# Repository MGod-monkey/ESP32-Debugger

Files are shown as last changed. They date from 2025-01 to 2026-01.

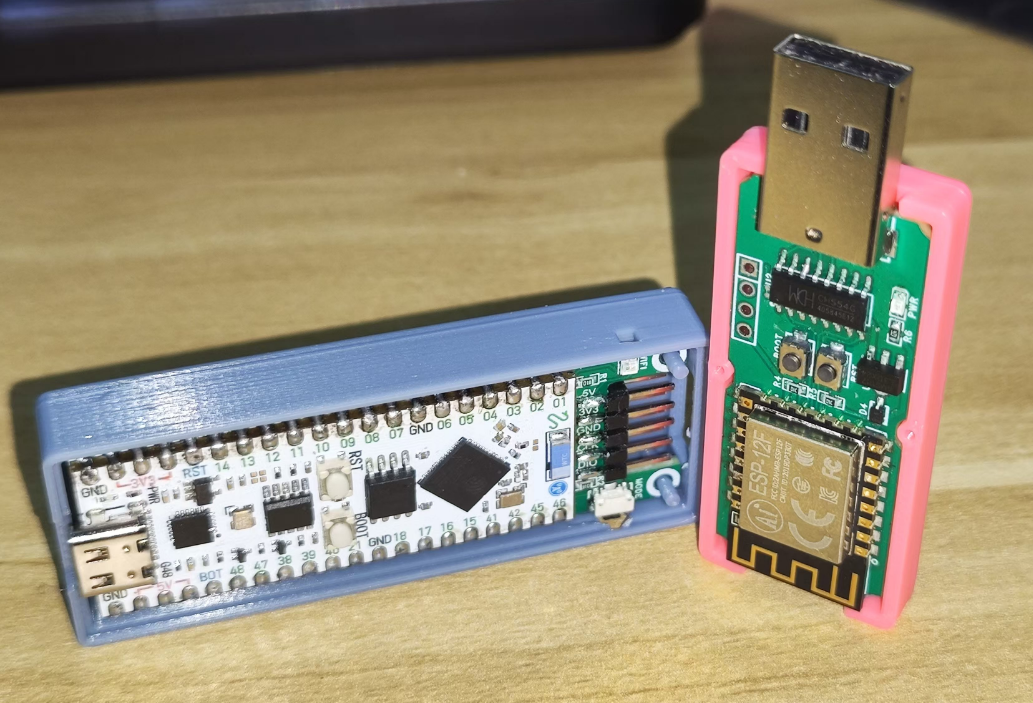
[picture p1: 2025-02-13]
assets/Snipaste_2024-12-25_23-06-20.png

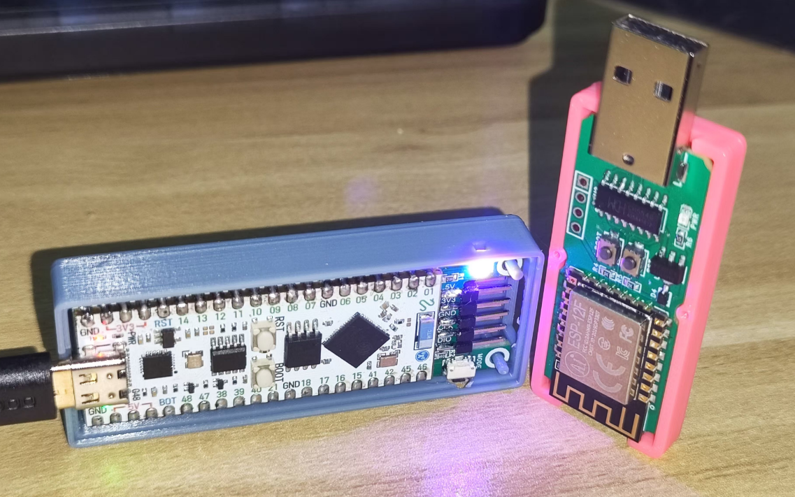
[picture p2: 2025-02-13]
assets/Snipaste_2024-12-25_23-15-52.png

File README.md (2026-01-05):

> 代码基于ESP-IDF v5.x开发，Keil工程基于MDK-ARM v5.29开发，其他版本未测试
> 本项目基于MIT协议开源，欢迎大家使用和转载，转载请注明出处
>

[toc]

## B站演示视频：[【（开源）基于ESP32S3立创开发板的多功能调试器（STM32 / ESP32 / Arduino调试和烧录）】 ](https://www.bilibili.com/video/BV1NECJYyEaa/?share_source=copy_web&vd_source=be68408916a9ed6715c50a7c23ca43b6)

## 项目简介

1. 接收机基于立创ESP32S3R8N8开发板制作，可独立运行，也可搭配发送机运行，接收机可以搭配发送机实现即插即用，无需上位机和WIFI，即可远程调试和开发
2. 接收机支持支持SWD和JTAG协议，支持 OpenOCD/pyOCD，支持虚拟串口，可同时进行仿真调试和串口收发
3. 接收机支持有线调试和无线调试的切换，通过MODE按钮长按进行模式切换
4. 接收机内置Web服务，可通过访问接收机IP来实现简单的WebSerial调试
5. 接收机支持向目标板供电（5V、3.3V），以及从目标板取电（5V、3.3V）两种方式进行工作
6. 接收机带状态指示灯，可提示当前调试模式，WIFI信号强度等
7. 烧录速度大于10KB/s，串口通信波特率可设置1M及以上
8. 接收机支持使用串口给Arduino等设备烧录固件，支持Arduino的串口烧录协议

## 实物展示
| 实物正面图 | 实物背面图 |
| --- | --- |
|  |  |





## 原理解析（硬件说明）


	本项目的发送端硬件由**CH554G单片机**和**ESP12F无线模块**组成。CH554G 是一款兼容 MCS51 指令集并支持 USB 2.0 的高性能单片机，主要负责与PC端进行USB 通信。通过USB连接PC，生成 **CMSIS DAP调试设备**和**CDC 虚拟串口设备**，提供调试和串口通信功能。同时，CH554G通过UART与ESP12F无线模块连接。ESP12F 负责**创建无线热点（AP）**并**搭建 TCP 服务器**，等待接收端设备连接，从而实现数据的**无线透传**功能，**CHECK信号线**用于判断是否与**接收机建立连接**。**SY6280AAC**用于**防止意外过压**或**过流**导致的电路损坏，保障系统的安全性和稳定性，限流大小为**I(A)=6800/R2=1A**。



	接收端硬件主要由立创**ESP32S3R8N8 开发板**构成，通过移植 **DAPLink** 代码实现 **CMSIS-DAP** 功能，用于支持 **SWD** 和 **JTAG** 协议的调试功能。在有线调试模式下，基于**TinyUSB框架**实现USB通信功能，其中 **CMSIS-DAP** 设备和 **CDC 虚拟串口**设备通过TinyUSB的**HID**和**CDC**模块完成初始化和数据传输，支持在PC端的 Keil 环境中进行调试和串口通信。
	同时，接收机还实现了无线调试功能，利用 ESP32S3内置的**Wi-Fi模块**，连接到发送端创建的AP热点，并与**TCP服务器**建立连接，实现**无线数据传输**，从而支持无线下载调试和串口透传。
	此外，接收端还支持**独立运行**，通过连接到与PC端相同的Wi-Fi网络，在局域网内与PC端建立连接，结合**USBIP技术栈**（通过网络远程共享和访问USB设备的一种技术)，可以实现**远程调试**和**串口透传**功能，也能结合**elaphureLink上位机**实现快速的连接和keil的远程下载调试。

## 软件烧录
### 发送机烧录
	1.发送端需要烧录ESP12F和CH554G的固件，CH554G需要使用`WCHISPTool_Setup`烧录工具进行烧录，如果是全新的CH554G，默认插上电脑的USB，上电就会进入Boot模式，此时可以通过工具进行识别和烧录，如果是已经烧录过的CH554G则需要短接U2旁边的触点，然后插上电脑上电，才能通过工具进行烧录，烧录固件为`firmware/ch554.hex`





	ESP12F烧录通过引出来的串口接口进行烧录，需要用一个USB转TTL下载工具，使用乐鑫官方下载工具flash_download_tool进行烧录，长按BOOT按钮，然后短按RST按钮，松开BOOT按钮即可进入ESP12F的下载模式



	`flash_download_tool`选择ESP8266, 然后选择固件`firmware/ESP12F.ion.bin`进行烧录，如果点击开始后没反应，先判断一下串口是否连接对了，再判断一下ESP12F是否进入的下载模式





	烧录完成后，重新接入电脑，发送机就可以正常使用了，此时ESP12F会生成一个AP热点，热点名称：`MGodmonkey`,密码：`1234567890`（后续会考虑给ESP12F添加OTA更新的功能，让其烧录一次代码就能无限远程更新）

### 接收机烧录
	接收机的固件有两种，一个是搭配USBIP技术栈独立使用的单机模式固件，一个是搭配发送机使用的双机模式固件，两种固件下载方式都是一样的。
`flash_download_tool`选择ESP32S3, LoadMode选择UART,ESP32S3立创开发板连接电脑后会生成两个串口，一个是USB-OTG的USB串行设备，一个是连接CH340K的串口设备，选择第二个串口进行烧录即可





	`flash_download_tool`的分区设置要严格按照图中的进行设置，否则可能会出错，烧录的固件在`firmware/Single_Mode`或`firmware/Double_Mode`中

| 文件 |  索引 |
| :---: | :-----: |
| bootloader.bin | 0x0 |
|  ESP32_DAPLink.bin | 0x20000 |
| partition-table.bin  | 0x8000  |
| ota_data_initial.bin | 0xf000  |



## 外壳说明
发送机的外壳可以在淘宝上买到公版的电流计亚克力外壳来使用：
https://item.taobao.com/item.htm?_u=l2otn78942e7&id=536932505082&spm=a1z09.2.0.0.6b752e8dQAsOIG

## 接线方式
根据接收机上的引脚进行接线

SW协议接线：

| 符号  | 对应引脚 |
| :---: | :---: |
|  3V3  | 3V3 |
|  GND  | GND |
| SWDIO | DIO |
| SWCLK | CLK |

JTAG协议接线：

|  符号  | 对应引脚 |
| :----: | :---: |
|  3V3 | 3V3 |
|  GND | GND |
|  TMS | DIO |
|  TCK | CLK |
|  TDI | TDI |
|  TDO | TDO |
| nRESET | RST（可不接） |

UART接线：

| 符号 | 对应引脚 |
| :--: | :---: |
| TXD  | TXD |
| RXD  | RXD |

## 指示灯说明

| 指示灯 | 状态 |
| :---: | :---: |
|  橙色呼吸 | 启动中 |
| 橙色闪烁2次 | 模式切换中 |
|  紫色常亮 | 有线模式 |
|  红色常亮 | 等待连接WIFI / 启动错误 |
|  绿色常亮 | 连接WIFI成功并信号很好  |
|  绿色呼吸 | 连接WIFI成功并信号一般  |
|  红色闪烁 | 连接WIFI成功并信号较差  |

## 使用步骤

> **Keil MDK-ARM**版本需要**5.29**及以上版本，其他软件暂未测试

### 单接收机使用

1. 有线模式（SWD/JTAG）

   有线模式下直接连接usb到电脑上即可，另一边通过SWD/JATG连接待调试的设备，启动成功后会在电脑上生成一个U盘，这是DAPLink的特性（但离线文件下载功能还没实现，，，所以暂时还不能通过传固件文件到u盘上来实现自动烧录），同时会生成一个虚拟串口
   
   

	此时打开keil工程，点击魔法棒->debug->Use选择CMSIS-DAP Debugger->点击Settings后即可看到设备信息，值得说明的是，JTAG协议下有个小bug，就是有时会显示**SWD/JTAG Communication Failure**，此时**Max Clock**设置为**5MHz或低于10MHz下的任意频率**即可，然后就能正常显示设备了，此时也能正常切换回10MHz下的频率进行使用了（应该是软件代码问题，暂未找到bug原因）





2. 有线模式（UART）

   串口支持接收发，支持在SWD/JTAG调试下一起使用，串口频率可以任意设置，可设置到超过1M波特率

   xx

3.无线模式(SWD/JTAG)

	单机无线模式下keil需要搭配开源上位机`elaphureLink`（`elaphureLink`不支持JTAG协议）或者USBIP（支持SWD/JTAG协议）来使用。双击`elaphureLink.Wpf.exe`打开软件，第一次使用需要安装keil驱动，由于代码已经设置好了mDNS，因此无需知道设备IP也可直接连接



	打开keil工程，点击魔法棒->debug->Use选择CMSIS-DAP Debugger->点击Settings后即可看到设备信息



	USBIP使用需要知道提前ESP32S3的IP地址，并且与ESP32S3同一网络下，有线连接开发板，串口助手连接CH340K开头的设备串口即可看到ESP32S3的串口调试信息，成功连接WIFI后会显示IP地址，一般情况下这个IP不会改变，如果家里设备情况多的话，路由器可能会给其重新分配一个IP，此时就需要重新获取了



	**cmd终端**中输入`.\usbip.exe attach -r 设备IP -b 1-1`即可连接设备并且在设备管理器中即可看到生成的**无线CMSIS-DAP**，打开keil工程，点击魔法棒->debug->Use选择CMSIS-DAP Debugger->点击Settings后即可看到设备信息

xxx



4.无线模式(UART)

无线串口传输跟有线串口传输功能是一样的，不过接收机内置了一个Web服务，可以通过访问ESP32S3的IP地址来使用**WebSerial**功能，在网页上发送数据到接收机的串口中



### 搭配发送机使用

> 发送机能实现单接收机的所有功能，只不过接收机自带WIFI，无需上位机和局域网，通过ESP12F与ESP32S3的WIFI模块进行通信，实现远程下载调试和串口传输
>

## WIFI配置说明

### 默认WIFI配置
接收机的WIFI配置位于 `main/include/wifi_configuration.h` 文件中，默认预置了3个WIFI信息：

1. 发送机AP热点 (默认优先级最高)
   - SSID: `MGodmonkey`
   - 密码: `1234567890`

2. 备用热点
   - SSID: `DAP`
   - 密码: `12345678`

3. 实验室网络
   - SSID: `INSS-Lab_2.4G`
   - 密码: `G-STAR1211`

### 使用说明
- 接收机会按顺序尝试连接配置文件中的WIFI
- 单机模式使用时，需要确保能连接到其中一个WIFI
- 可以通过以下方式添加自己的WIFI

## 注意事项

* 如果仅需要单机使用，直接打样接收机的板子即可
* 单机模式需要搭配`elaphureLink`或`usbip`来使用
* 接收机3D外壳底座的按键部分打印出来需要轻轻的向外掰，注意是轻轻的哦

## 总结

> 该项目是匆匆忙忙赶工期造出来的，因为本人处于研究生开题阶段，也在忙着找创新点，经历过的应该都知道这个阶段的苦哈，项目基本功能已经实现，但还有很多bug和不足，后续会慢慢补充和完善
> 本项目借鉴了以下优秀的开源项目：
>
> - [https://github.com/windowsair/wireless-esp8266-dap](https://github.com/windowsair/wireless-esp8266-dap)
> - [ttps://oshwhub.com/q837877663/duo-gong-neng-wu-xian-xia-zai-qi](https://oshwhub.com/q837877663/duo-gong-neng-wu-xian-xia-zai-qi)
> - []()

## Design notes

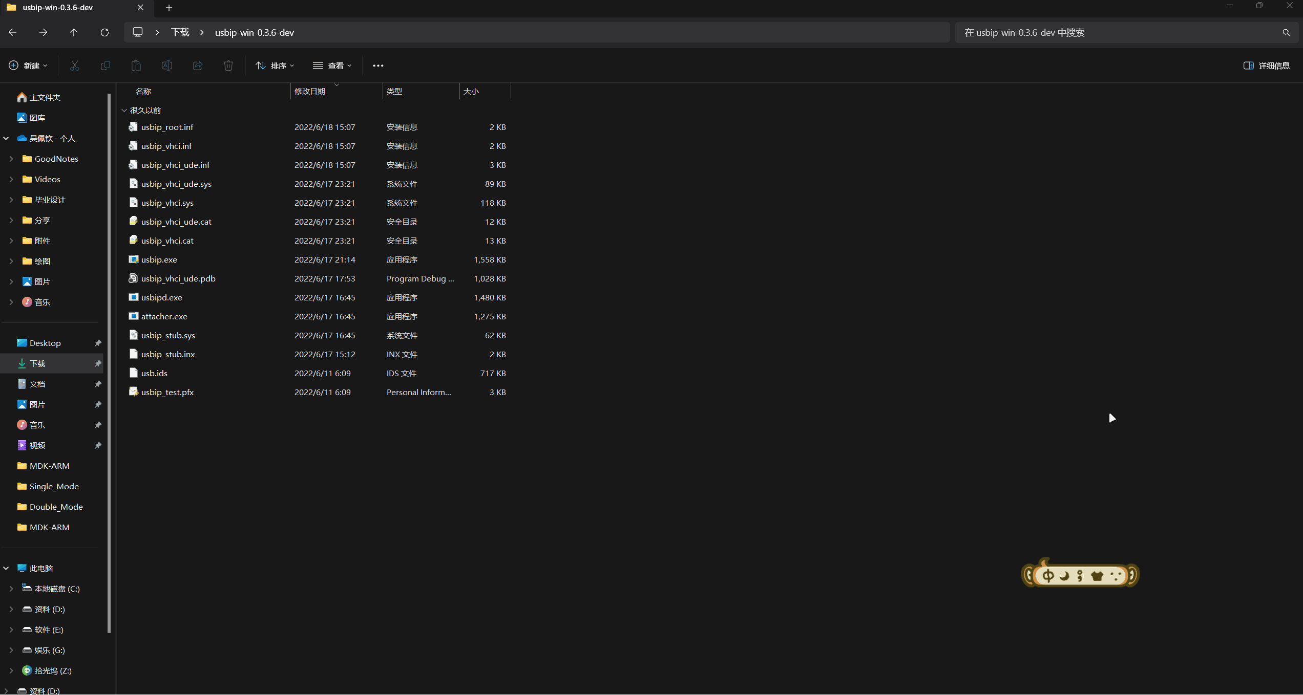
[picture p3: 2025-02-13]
assets/usbip.gif

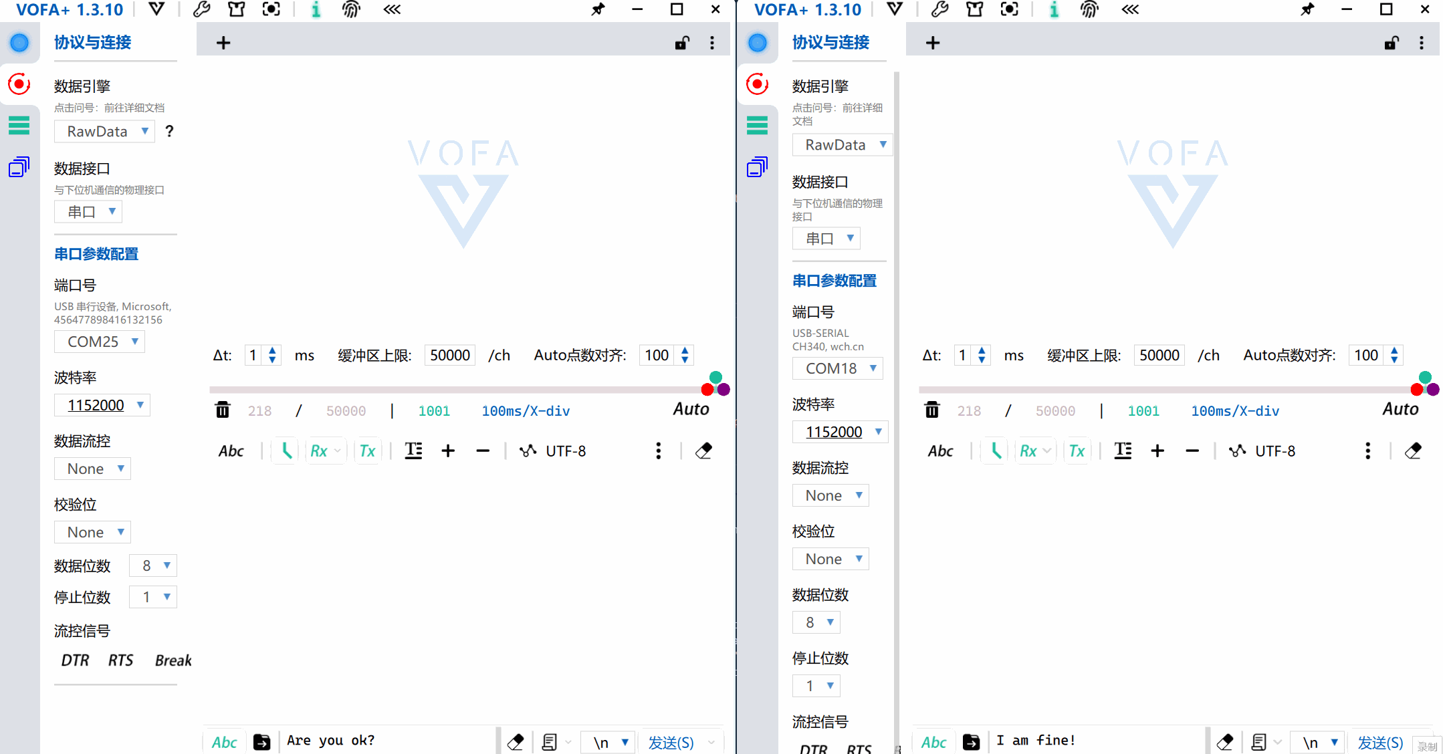
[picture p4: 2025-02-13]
assets/uart.gif

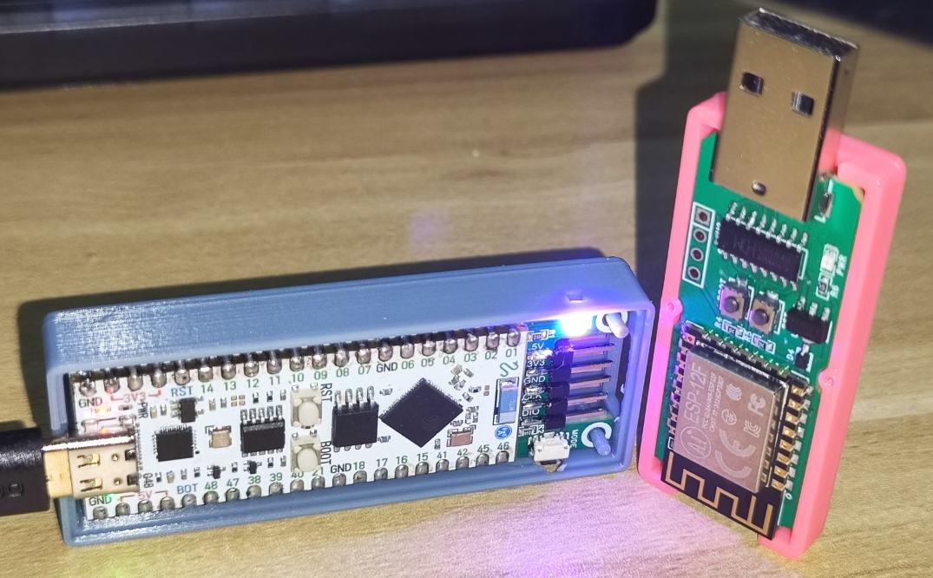
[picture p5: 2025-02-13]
assets/Snipaste_2024-12-25_23-15-13.png

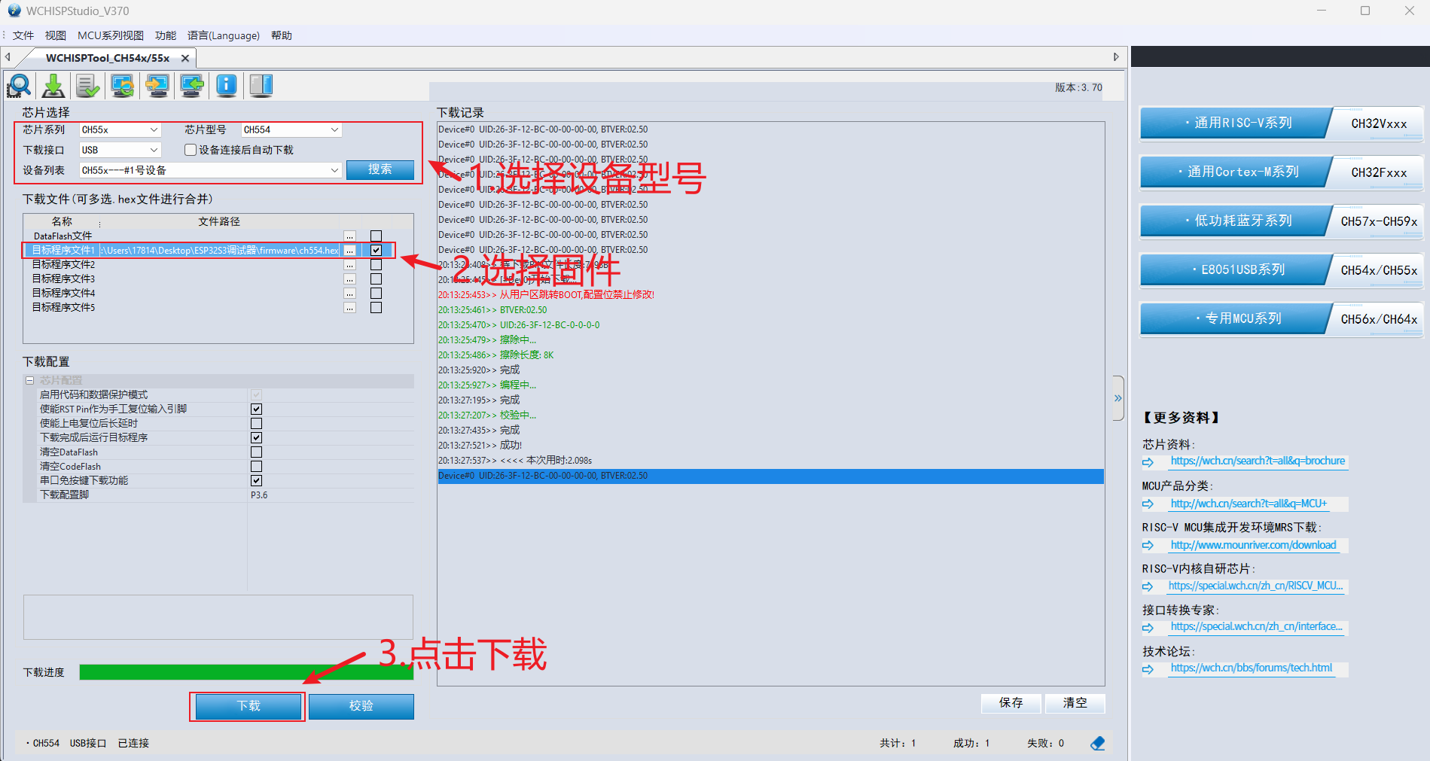
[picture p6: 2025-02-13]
assets/ch554烧录.png

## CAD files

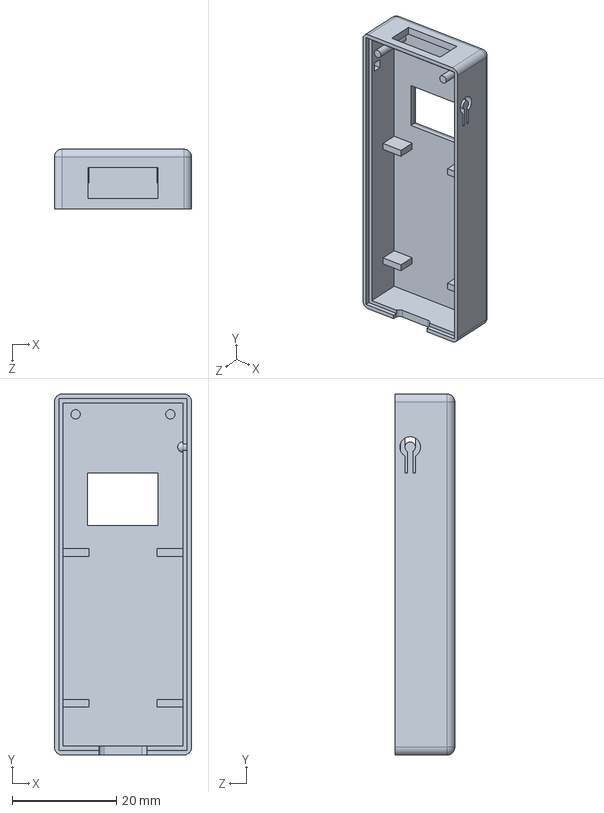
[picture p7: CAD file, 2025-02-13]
3D_Model/接收机底部.SLDPRT
26.4 x 69.4 x 11.5 mm

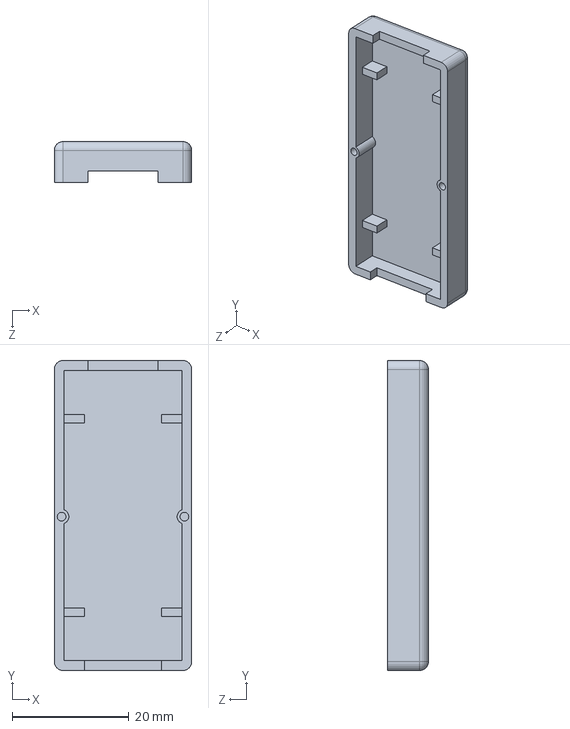
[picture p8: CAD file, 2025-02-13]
3D_Model/发送机底部.SLDPRT
23.5 x 53.0 x 7.00 mm

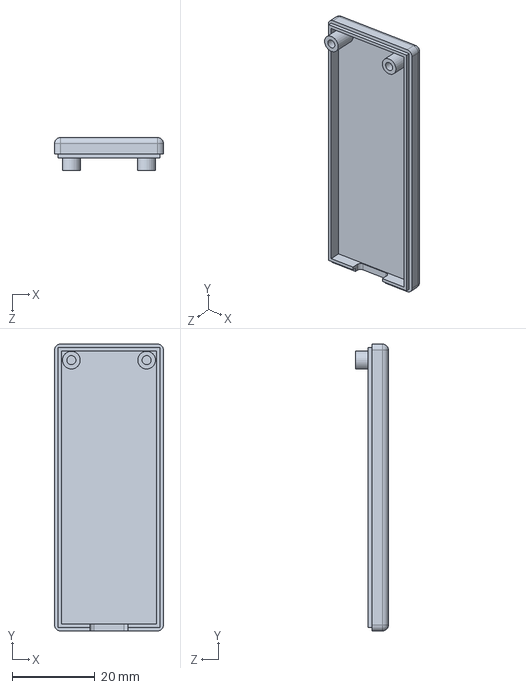
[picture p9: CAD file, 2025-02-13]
3D_Model/接收机顶盖.SLDPRT
26.4 x 69.4 x 8.00 mm

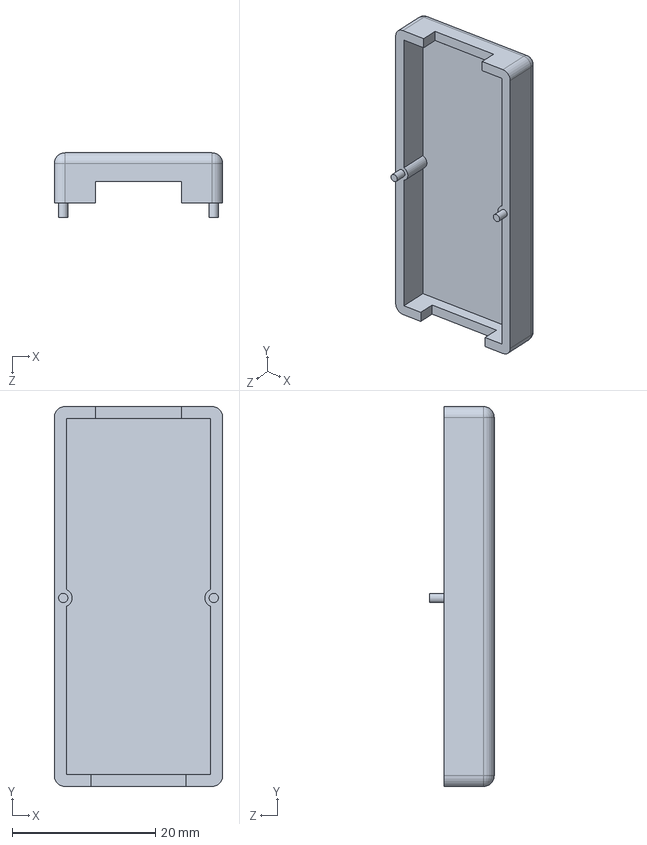
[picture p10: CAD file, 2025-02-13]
3D_Model/发送机顶盖.SLDPRT
23.5 x 53.0 x 9.00 mm

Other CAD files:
3D_Model/发送机底部.STL
3D_Model/发送机顶盖.STL
3D_Model/接收机底部.STL
3D_Model/接收机顶盖.STL

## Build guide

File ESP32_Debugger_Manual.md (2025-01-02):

# ESP32无线调试器操作手册

## 一、产品介绍

这是一款基于ESP32S3的无线调试器，由发送机和接收机两部分组成。接收机默认烧录双机模式固件，可与发送机配对使用。支持以下主要功能：

- SWD和JTAG协议调试
- 虚拟串口通信
- 有线/无线模式切换
- 可选供电方式(5V/3.3V)
- LED状态指示
- 高速下载(>10KB/s)
- Arduino串口烧录支持

## 二、使用准备

### 1. 有线调试模式
1. 直接通过USB将接收机连接到电脑
2. 无需使用发送机
3. 系统将识别出U盘和虚拟串口设备

### 2. 无线调试模式(双机)
1. 将发送机插入电脑USB端口
2. 等待系统识别出虚拟串口设备
3. 发送机会自动创建WiFi热点:
   - 热点名称: MGodmonkey
   - 密码: 1234567890
4. 接收机会自动连接到发送机的WiFi热点

### 3. 无线调试模式(单机)
> 单机模式需要先烧录单机固件,并确保电脑和接收机连接到同一个WiFi网络

#### WiFi配置说明
接收机内置了3个WiFi配置:
1. 配置一:
   - SSID: ESP32_DAP
   - Password: 12345678
2. 配置二:
   - SSID: CMSIS-DAP
   - Password: 12345678
3. 配置三:
   - SSID: DAP
   - Password: 12345678

请将电脑连接到以上任一WiFi,或修改源码中的WiFi配置信息后重新烧录。

#### 使用elaphureLink (仅支持SWD)
1. 解压elaphureLink压缩包，运行elaphureLink.Wpf.exe
2. 首次使用需要安装驱动:
   - 打开elaphureLink
   - 点击"安装"
   - 按提示完成安装
3. 点击开始透传按钮，等待连接成功
4. 连接成功后在Keil中配置:
   - 打开项目设置(Options for Target)
   - 选择Debug选项卡
   - Use栏选择"CMSIS-DAP Debugger"
   - 点击Settings确认设备已识别
   - 如使用JTAG模式，将Max Clock先设为5MHz或低于5MHz，显示识别到设备后，则可设置回10MHz
5. 开始调试下载

#### 使用USBIP (支持SWD/JTAG)
1. 下载USBIP工具包并解压
2. 通过串口查看接收机IP地址:
   - 连接接收机的CH340串口
   - 波特率115200
   - 查看输出的IP地址信息
3. 在CMD中运行:
   ```
   cd [USBIP工具目录]
   usbip.exe attach -r [接收机IP] -b 1-1
   ```
4. 等待系统识别虚拟USB设备
5. 在Keil中按有线模式相同方式配置
6. 开始调试下载

## WIFI配置说明

### 默认WIFI配置
接收机的WIFI配置位于 `main/include/wifi_configuration.h` 文件中，默认预置了3个WIFI信息：

1. 发送机AP热点 (默认优先级最高)
   - SSID: `MGodmonkey`
   - 密码: `1234567890`

2. 备用热点
   - SSID: `DAP`
   - 密码: `12345678`

3. 实验室网络
   - SSID: `INSS-Lab_2.4G`
   - 密码: `G-STAR1211`

### 使用说明
- 接收机会按顺序尝试连接配置文件中的WIFI
- 单机模式使用时，需要确保能连接到其中一个WIFI
- 可以通过以下方式添加自己的WIFI：
  - 修改`main/include/wifi_configuration.h`文件中的WIFI信息
  - 重新烧录接收机固件  

## 二、软件准备

### 所需软件包
1. CH554.zip - CH554程序源码
2. ESP12F.zip - ESP12F程序源码
3. firmware.zip - 所有直接烧录的固件(包含单机模式和双机模式)
4. WCHISPTool Setup.zip - CH554烧录工具
5. flash download tool 3.9.7.zip - ESP芯片烧录工具
6. elaphureLink Windows x64 release.zip - 单机模式无线调试上位机
7. usbip-win-0.3.6-dev.zip - 单机模式无线调试工具

### 3D打印文件
1. 发送机底部.STL
2. 发送机顶盖.STL
3. 接收机底部.STL
4. 接收机顶盖.STL

## 三、固件烧录

### 发送机烧录
1. CH554烧录:
   - 使用WCHISPTool工具
   - 新的CH554默认上电进入Boot模式
   - 已烧录过的CH554需短接U2旁触点后上电
   - 选择firmware/ch554.hex进行烧录

2. ESP12F烧录:
   - 使用flash_download_tool工具
   - 选择ESP8266芯片
   - 长按BOOT按钮，短按RST按钮，松开BOOT进入下载模式
   - 选择firmware/ESP12F.ion.bin进行烧录
   - 烧录完成后重新上电，将自动创建WiFi热点

### 接收机烧录
1. 使用flash_download_tool工具:
   - 选择ESP32S3芯片
   - LoadMode选择UART
   - 选择CH340K串口设备
   
2. 分区表设置:
   | 文件 | 地址 |
   |------|------|
   | bootloader.bin | 0x0 |
   | ESP32_DAPLink.bin | 0x20000 |
   | partition-table.bin | 0x8000 |
   | ota_data_initial.bin | 0xf000 |

## 四、LED指示灯状态说明

| LED状态 | 含义 |
|---|---|
| 橙色呼吸 | 设备启动中 |
| 橙色闪烁2次 | 正在切换模式 |
| 紫色常亮 | 有线模式 |
| 红色常亮 | 等待连接WIFI或启动错误 |
| 绿色常亮 | WIFI连接成功且信号良好 |
| 绿色呼吸 | WIFI连接成功且信号一般 |
| 红色闪烁 | WIFI连接成功但信号较差 |

## 五、接线说明

### SWD模式接线
- 3V3 → 3V3
- GND → GND  
- SWDIO → DIO
- SWCLK → CLK

### JTAG模式接线
- 3V3 → 3V3
- GND → GND
- TMS → DIO
- TCK → CLK
- TDI → TDI
- TDO → TDO
- nRESET → RST (可选)

### UART接线
- TXD → TXD
- RXD → RXD
> 串口接线对应的是TTL烧录器上的符号，如果在Arduino设备烧录时出现问题，可以将RXD和TXD互换后重试

## 六、调试操作步骤

> 默认烧录双机模式固件，如需单机使用需重新烧录单机固件

### 1. 有线调试模式
1. 通过USB连接接收机到电脑
2. 按照接线说明连接目标板
3. 在Keil MDK中配置:
   - 打开项目设置(Options for Target)
   - 选择Debug选项卡
   - Use栏选择"CMSIS-DAP Debugger"
   - 点击Settings确认设备已识别
   - 如使用JTAG模式，将Max Clock先设为5MHz或低于5MHz，显示识别到设备后，则可设置回10MHz
4. 点击Download按钮下载程序
5. 点击Start/Stop Debug Session进入调试

### 2. 无线调试模式(双机)
1. 插入发送机，等待系统识别
2. 确认接收机已连接到发送机WiFi(查看LED状态)
3. 连接目标板到接收机
4. 在Keil MDK中配置:
   - 打开项目设置(Options for Target)
   - 选择Debug选项卡
   - Use栏选择"CMSIS-DAP Debugger"
   - 点击Settings确认设备已识别
   - 如使用JTAG模式，将Max Clock设为5MHz
5. 开始调试下载

### 3. Arduino设备烧录
1. 连接Arduino设备到接收机的UART接口
2. 打开Arduino IDE
3. 选择对应生成的虚拟串口
4. 点击上传按钮开始烧录
> 如遇烧录失败，尝试将RXD和TXD互换

### 4. 串口通信
1. 有线模式:
   - 连接虚拟串口设备
   - 波特率可设置超过1M
   - 支持串口收发数据
   - 支持与调试同时使用
   
2. 无线模式:
   - 双机模式下直接使用发送机的虚拟串口
   - 单机模式可使用内置WebSerial功能
   - 支持与调试同时使用

#### WebSerial使用说明
1. 设备连接成功后，在浏览器中访问 http://[接收机IP]
2. 网页界面提供以下功能：
   - 实时串口数据显示
   - 可调节波特率（最高115200）
3. 特点：
   - 无需安装额外软件
   - 支持多客户端同时访问
   - 跨平台兼容（支持手机访问）

### 3. 无线调试模式(单机)
#### 使用elaphureLink
1. 打开elaphureLink软件
2. 点击开始透传按钮，等待连接成功
3. 连接成功后在Keil中配置:
   - 按有线模式相同方式设置
   - 确保elaphureLink保持运行
4. 开始调试下载

#### 使用USBIP
1. 获取接收机IP地址
2. 在CMD中运行:
   ```
   cd [USBIP工具目录]
   usbip.exe attach -r [接收机IP] -b 1-1
   ```
3. 等待系统识别虚拟USB设备
4. 在Keil中按有线模式相同方式配置
5. 开始调试下载

## 七、注意事项

1. Keil MDK版本要求5.29及以上
2. JTAG模式可能需要调整时钟频率以解决通信问题
3. 使用无线模式时，确保接收机与发送机距离适中
4. 建议在开阔环境下使用无线功能
5. 默认烧录双机模式固件，如需单机使用需重新烧录单机固件
6. 单机模式下使用USBIP时，确保电脑和接收机在同一局域网内
7. 使用elaphureLink时需保持软件运行，关闭后将断开连接

## 八、已知的BUG

1. JTAG模式下，JTAG时钟频率为10MHz时，无法正常通信，需要先设置为5MHz或低于5MHz的频率后才能正常通信，正常通信后可设置回10MHz
2. SWD模式下，时钟频率为10MHz以下时，无法正常通信
> 以上bug暂时确定为软件问题，后续会修复

## 九、故障排除

1. 无法识别设备
   - 检查USB连接
   - 重新插拔设备
   - 确认驱动安装正确

2. 无线连接不稳定
   - 检查信号强度(观察LED状态)
   - 调整设备间距离
   - 减少环境中的干扰源
   - 必要时切换到有线模式

3. 下载调试失败
   - 检查接线是否正确
   - 确认目标板供电正常
   - JTAG模式下尝试降低时钟频率
   - 确认Keil配置正确

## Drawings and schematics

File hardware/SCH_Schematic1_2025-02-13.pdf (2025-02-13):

# CH554G电路

# ESP12F模块

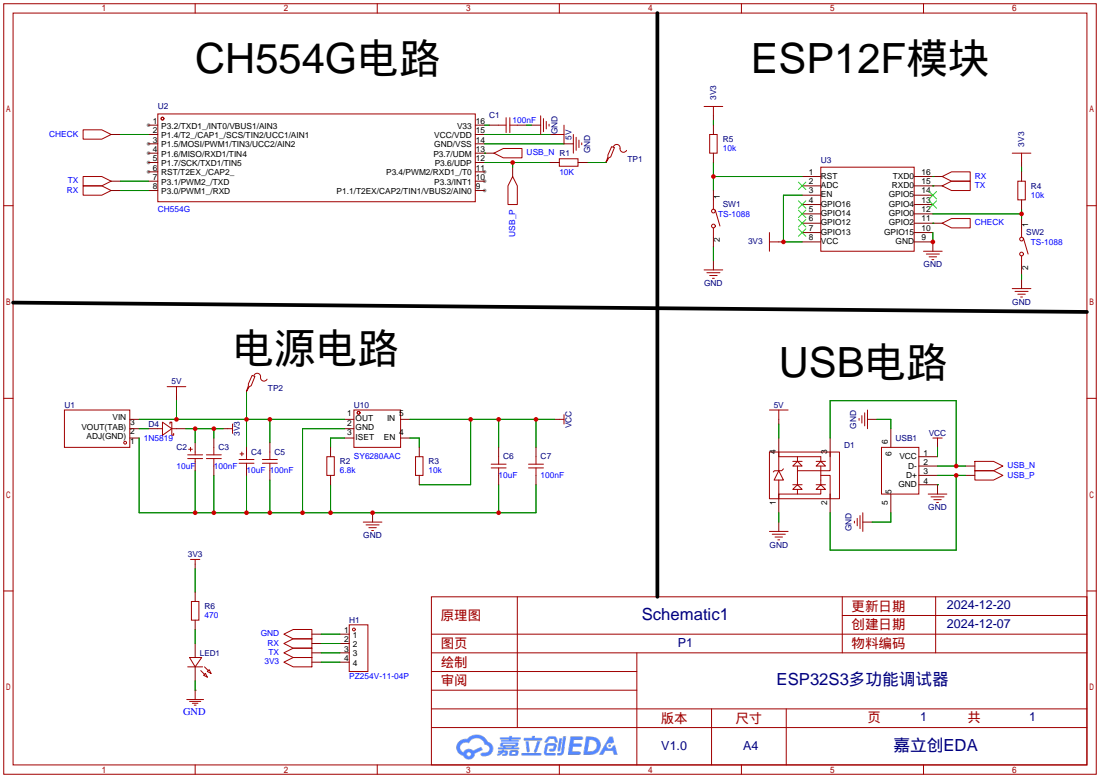
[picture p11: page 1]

P3.3/INT1 10 P3.4/PWM2/RXD1_/T0 11 P3.6/UDP 12 P3.7/UDM 13 GND/VSS 14 VCC/VDD 15 V33 16

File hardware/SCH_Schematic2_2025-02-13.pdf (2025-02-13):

# ESP32S3模块

# 扩展电路

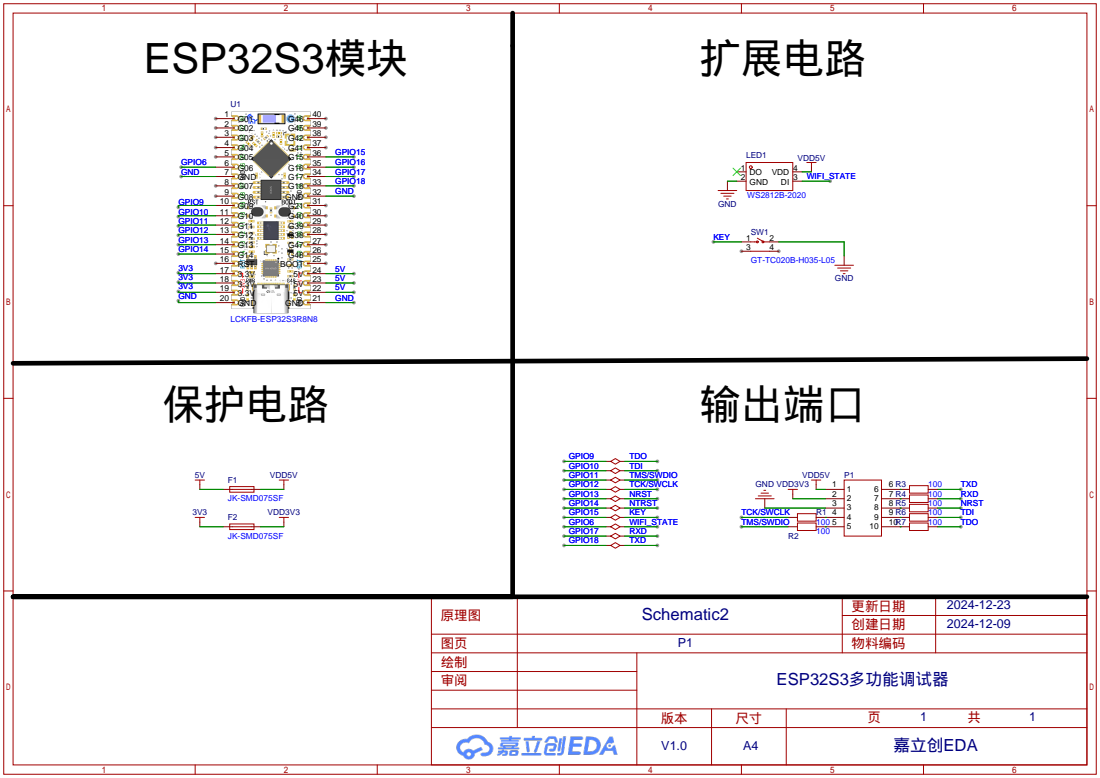
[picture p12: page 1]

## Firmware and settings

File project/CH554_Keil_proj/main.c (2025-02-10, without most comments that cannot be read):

/********************************** (C) COPYRIGHT ******************************
* File Name          :Compound_Dev.C											
* Author             : WCH                                                      
* Version            : V1.0                                                     
* Date               : 2017/03/15                                               
* Description        : A demo for USB compound device created by CH554, support 
					   keyboard and mouse, and HID compatible device.           
********************************************************************************/
#include ".\Public\CH554.H"
#include "Compound.h"
#include ".\Public\debug.h"
#include <stdio.h>
#include <string.h>
#include ".\Public\GPIO.H"
sbit check = P1^4;
UINT8 flag1_1 = 1;


extern UINT8 	FLAG;												  // Trans complete flag
extern UINT8 	EnumOK;												// Enum ok flag	

UINT8 Res;	
UINT8 D1_len=0,D2_len=0;
UINT8 Flag_3=0,Flag_4=0;
UINT8X USART_RX_BUF[66];
UINT8X USART3_RX_BUF[140];




UINT16 USART_RX_STA=0;
UINT16 USART3_RX_STA=0;
UINT16 num_1 =0,num_2=0;  				

void DAP_Thread(void)
{
    UINT8I num;

    if (USB_RequestFlag)
    {
		CH554UART0SendByte(0x66);
		num_2 = 0;
		num_1= 63;
		while(1)
		{
			num_2 += Ep3Buffer[num_1];
			if(num_2)break;
			num_1--;
		}
		CH554UART0SendByte(num_1+1);
		for(num=0;num<num_1+1;num++)
		{	
			CH554UART0SendByte(Ep3Buffer[num]);
		}
		while((USART_RX_STA&0x8000)==0);		
		USART_RX_STA = 0;	
		for(num=0;num<64;num++)
		{
			Ep3Buffer2[num] = USART_RX_BUF[num];//???1????
		}
		UEP3_CTRL = UEP3_CTRL & ~ MASK_UEP_R_RES | UEP_R_RES_ACK; //enable receive
	    UEP3_T_LEN = 64;
	    UEP3_CTRL = UEP3_CTRL & ~ MASK_UEP_T_RES | UEP_T_RES_ACK; //enable send
		USB_RequestFlag = 0;
    }
}

void main( void )
{
	UINT8I num=0,lenth=0;
	UINT16X timeout;  // 使用CH554的XDATA存储类型
	
	CfgFsys();//时钟选择配置
	mDelaymS(5);//修改频率等待内部晶振稳定,关键
	Port1Cfg(3,4);                                                             //P16推挽输出模式
	
	// 初始化调试串口
	mInitSTDIO();
	printf("System Init Start\n");
	
	USBDeviceInit();//初始化USB设备
	printf("USB Device Init Done\n");
	
	EA = 1;	
	UEP1_T_LEN = 0;
	UEP2_T_LEN = 0;
	UEP3_T_LEN = 0;
	Endp2Busy = 0;
	
	while(flag1_1)
	{
		if(check == 0)
		{
			flag1_1=0;
		}
		mDelaymS(100);  
	}
	
	for(num=0;num<64;num++)
	{
		USART_RX_BUF[num]= 0;
	}
	
	timeout = 0;
	while(!UsbConfig && timeout < 1000) { // 等待USB枚举完成
		mDelaymS(1);
		timeout++;
		if(timeout % 100 == 0)
		{
			printf("Waiting for USB Config: %d ms\n", timeout);
			// 输出USB状态寄存器值以便调试
			printf("USB_CTRL: %02X, UDEV_CTRL: %02X\n", USB_CTRL, UDEV_CTRL);
		}
	}
	
	if(!UsbConfig) {
		printf("USB Enumeration Failed\n");
		while(1) {  // USB枚举失败
			mDelaymS(100);
		}
	}
	printf("USB Enumeration Success\n");
	
	while(1)
	{
//		if(USART_RX_STA&0x8000)
//		{		
//			USART_RX_STA = 0;	
//			for(num=0;num<64;num++)
//			{
//				CH554UART0SendByte(USART_RX_BUF[num]);
//			}
//		}

//		{

//			{

//				{
//					lenth = USBByteCount;		

//					memcpy(Ep2Buffer+MAX_PACKET_SIZE,Ep2Buffer,lenth);


//					Endp2Busy = 1;

//					USBByteCount= 0;				
//				}				
//			}
//		}
		DAP_Thread();
       	if (USBByteCount)
        {
			lenth = USBByteCount;
			CH554UART0SendByte(0x67);
			CH554UART0SendByte(lenth);
			for(num=0;num<lenth;num++)
			{
				CH554UART0SendByte(Ep2Buffer[num]);
			}
//            CH554UART0SendByte(Ep2Buffer[USBBufOutPoint++]);
            USBByteCount=0;
            if (USBByteCount == 0)
                UEP2_CTRL = UEP2_CTRL & ~ MASK_UEP_R_RES | UEP_R_RES_ACK;
        }
		if(USBD0)
		{
//			Ep2Buffer[64] =   USBD0;


//			Endp2Busy = 1;
			
			CH554UART0SendByte(0x68);
			CH554UART0SendByte(1);
			CH554UART0SendByte(USBD0);
			USBD0 = 0;
		}
		if(USART3_RX_STA&0x8000)
		{
			if (!Endp2Busy)
			{
				lenth = USART3_RX_STA&0X0FFF;
				if(lenth<64)
				{
					memcpy(Ep2Buffer+64,&USART3_RX_BUF[0],lenth);
					UEP2_T_LEN = lenth;
					UEP2_CTRL = UEP2_CTRL & ~ MASK_UEP_T_RES | UEP_T_RES_ACK;
					Endp2Busy = 1;
					USART3_RX_STA = 0;
				}else if(lenth==64)
				{
					memcpy(Ep2Buffer+64,&USART3_RX_BUF[0],lenth);
					UEP2_T_LEN = lenth;
					UEP2_CTRL = UEP2_CTRL & ~ MASK_UEP_T_RES | UEP_T_RES_ACK;
					Endp2Busy = 1;
					while(Endp2Busy);	
					UEP2_T_LEN = 0;
					UEP2_CTRL = UEP2_CTRL & ~ MASK_UEP_T_RES | UEP_T_RES_ACK;
					Endp2Busy = 1;
					USART3_RX_STA = 0;
				}else if(lenth>64)
				{
					for(num=0;num<(lenth/64);num++)
					{
						memcpy(Ep2Buffer+64,&USART3_RX_BUF[num*64],64);
						UEP2_T_LEN = 64;
						UEP2_CTRL = UEP2_CTRL & ~ MASK_UEP_T_RES | UEP_T_RES_ACK;
						Endp2Busy = 1;
						while(Endp2Busy);	
						UEP2_T_LEN = 0;
						lenth-=64;
					}
					memcpy(Ep2Buffer+64,&USART3_RX_BUF[num*64],lenth);
					UEP2_T_LEN = lenth;
					UEP2_CTRL = UEP2_CTRL & ~ MASK_UEP_T_RES | UEP_T_RES_ACK;
					Endp2Busy = 1;
					USART3_RX_STA = 0;
				}
			}
		}		
			
//		if(UartByteCount)
//				Uart_Timeout++;

//		{
//			lenth = UartByteCount;
//			if(lenth>0)
//			{
//				if(lenth>39 || Uart_Timeout>100)
//				{		
//					Uart_Timeout = 0;
//					UartByteCount -= lenth;			

//					Uart_Output_Point+=lenth;
//					if(Uart_Output_Point>=64)
//						Uart_Output_Point = 0;						


//					Endp2Busy = 1;
//				}
//			}
//		}
//        if (USBByteCount)
//        { 
//			if (!Endp2Busy)
//			{
//				memcpy(Ep2Buffer+64,&Ep3Buffer[0],64);
//				Uart_Output_Point+=64;


//				Endp2Busy = 1;
//			}
//        }		
    }
}

void Uart0_ISR(void) interrupt INT_NO_UART0
{
	if(RI)
	{
		Res = SBUF;
		if(((USART_RX_STA&0x8000)||(USART3_RX_STA&0x8000))==0)
		{
			if(((USART_RX_STA&0x4000)||(USART3_RX_STA&0x4000))==0)
			{
				if(Res==0x66)
				{
					USART_RX_STA|=0x4000;
					Flag_3 = 1;
				}else if(Res==0x67)
				{
					USART3_RX_STA|=0x4000;
					Flag_4 = 1;
				}else
				{
					USART_RX_STA = 0;
					USART3_RX_STA = 0;
				}
			}else if((((USART_RX_STA&0x4000))&&(~(USART3_RX_STA&0x4000))))
			{
				if(Flag_3)
				{
					D1_len = Res;
					Flag_3 = 0;
				}else
				{
					USART_RX_BUF[USART_RX_STA&0X0FFF]=Res ;
					USART_RX_STA++;
					if((USART_RX_STA&0x0FFF)==D1_len)USART_RX_STA|=0x8000;
				}
			}else if((((~USART_RX_STA&0x4000))&&((USART3_RX_STA&0x4000))))
			{
				if(Flag_4)
				{
					D2_len = Res;
					Flag_4 = 0;
				}else
				{
					USART3_RX_BUF[USART3_RX_STA&0X0FFF]=Res ;
					USART3_RX_STA++;
					if((USART3_RX_STA&0x0FFF)==D2_len)USART3_RX_STA|=0x8000;
				}
			}
		}else if((((USART_RX_STA&0x8000))&&(~(USART3_RX_STA&0x8000))))
		{
			if((USART3_RX_STA&0x4000)==0)
			{
				if(Res==0x67)
				{
					USART3_RX_STA|=0x4000;
					Flag_4 = 1;
				}else
				{
					USART_RX_STA = 0;
				}
			}else
			{
				if(Flag_4)
				{
					D2_len = Res;
					Flag_4 = 0;
				}else
				{
					USART3_RX_BUF[USART3_RX_STA&0X0FFF]=Res ;
					USART3_RX_STA++;
					if((USART3_RX_STA&0x0FFF)==D2_len)USART3_RX_STA|=0x8000;
				}
			}
		}else if(((~(USART_RX_STA&0x8000))&&((USART3_RX_STA&0x8000))))
		{
			if((USART_RX_STA&0x4000)==0)
			{
				if(Res==0x66)
				{
					USART_RX_STA|=0x4000;
					Flag_3 = 1;
				}else
				{
					USART_RX_STA = 0;
				}
			}else
			{
				if(Flag_3)
				{
					D1_len = Res;
					Flag_3 = 0;
				}else
				{
					USART_RX_BUF[USART_RX_STA&0X0FFF]=Res ;
					USART_RX_STA++;
					if((USART_RX_STA&0x0FFF)==D1_len)USART_RX_STA|=0x8000;
				}
			}
		}
		RI = 0;
	} 
}

/**************************** END *************************************/

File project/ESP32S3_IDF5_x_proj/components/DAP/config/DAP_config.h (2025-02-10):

/*
 * Copyright (c) 2013-2017 ARM Limited. All rights reserved.
 *
 * SPDX-License-Identifier: Apache-2.0
 *
 * Licensed under the Apache License, Version 2.0 (the License); you may
 * not use this file except in compliance with the License.
 * You may obtain a copy of the License at
 *
 * www.apache.org/licenses/LICENSE-2.0
 *
 * Unless required by applicable law or agreed to in writing, software
 * distributed under the License is distributed on an AS IS BASIS, WITHOUT
 * WARRANTIES OR CONDITIONS OF ANY KIND, either express or implied.
 * See the License for the specific language governing permissions and
 * limitations under the License.
 *
 * ----------------------------------------------------------------------
 *
 * $Date:        16. June 2021
 * $Revision:    V2.1.0
 *
 * Project:      CMSIS-DAP Configuration
 * Title:        DAP_config.h CMSIS-DAP Configuration File (Template)
 *
 *---------------------------------------------------------------------------*/

#ifndef __DAP_CONFIG_H__
#define __DAP_CONFIG_H__

#include <stdint.h>
#include <string.h>

#include "main/include/dap_configuration.h"
#include "main/include/wifi_configuration.h"

#include "components/DAP/include/cmsis_compiler.h"
#include "components/DAP/include/gpio_op.h"
#include "hal_gpio.h"
#include "components/DAP/include/spi_switch.h"

#include "freertos/FreeRTOS.h"
#include "freertos/task.h"

//**************************************************************************************************
/**
\defgroup DAP_Config_Debug_gr CMSIS-DAP Debug Unit Information
\ingroup DAP_ConfigIO_gr
@{
Provides definitions about the hardware and configuration of the Debug Unit.

This information includes:
 - Definition of Cortex-M processor parameters used in CMSIS-DAP Debug Unit.
 - Debug Unit Identification strings (Vendor, Product, Serial Number).
 - Debug Unit communication packet size.
 - Debug Access Port supported modes and settings (JTAG/SWD and SWO).
 - Optional information about a connected Target Device (for Evaluation Boards).
*/

//#ifdef _RTE_
//#include "RTE_Components.h"
//#include CMSIS_device_header
//#else
//#include "device.h"                             // Debug Unit Cortex-M Processor Header File
//#endif

/// Processor Clock of the Cortex-M MCU used in the Debug Unit.
/// This value is uDAP_Commosed to calculate the SWD/JTAG clock speed.
#define CPU_CLOCK 36000000U



//#define MAX_USER_CLOCK 16000000 ///< Specifies the max Debug Clock in Hz.

/// Number of processor cycles for I/O Port write operations.
/// This value is used to calculate the SWD/JTAG clock speed that is generated with I/O
/// Port write operations in the Debug Unit by a Cortex-M MCU. Most Cortex-M processors
/// require 2 processor cycles for a I/O Port Write operation.  If the Debug Unit uses
/// a Cortex-M0+ processor with high-speed peripheral I/O only 1 processor cycle might be
/// required.
#define IO_PORT_WRITE_CYCLES 2U ///< I/O Cycles: 2=default, 1=Cortex-M0+ fast I/0.

/// Indicate that Serial Wire Debug (SWD) communication mode is available at the Debug Access Port.
/// This information is returned by the command \ref DAP_Info as part of <b>Capabilities</b>.
#define DAP_SWD 1 ///< SWD Mode:  1 = available, 0 = not available.

/// Indicate that JTAG communication mode is available at the Debug Port.
/// This information is returned by the command \ref DAP_Info as part of <b>Capabilities</b>.
#define DAP_JTAG 1 ///< JTAG Mode: 1 = available, 0 = not available.

/// Configure maximum number of JTAG devices on the scan chain connected to the Debug Access Port.
/// This setting impacts the RAM requirements of the Debug Unit. Valid range is 1 .. 255.
#define DAP_JTAG_DEV_CNT 8U ///< Maximum number of JTAG devices on scan chain.

/// Default communication mode on the Debug Access Port.
/// Used for the command \ref DAP_Connect when Port Default mode is selected.
#if (DAP_SWD == 1)
#define DAP_DEFAULT_PORT        1               ///< Default JTAG/SWJ Port Mode: 1 = SWD, 2 = JTAG.
#elif (DAP_JTAG == 1)
#define DAP_DEFAULT_PORT        2               ///< Default JTAG/SWJ Port Mode: 1 = SWD, 2 = JTAG.
#else
#error Must enable DAP_SWD and/or DAP_JTAG
#endif

/// Default communication speed on the Debug Access Port for SWD and JTAG mode.
/// Used to initialize the default SWD/JTAG clock frequency.
/// The command \ref DAP_SWJ_Clock can be used to overwrite this default setting.
#define DAP_DEFAULT_SWJ_CLOCK 1000000U ///< Default SWD/JTAG clock frequency in Hz.
// <<<<<<<<<<<<<<<<<<<<<<<<<<<<<1MHz

/// Maximum Package Buffers for Command and Response data.
/// This configuration settings is used to optimize the communication performance with the
/// debugger and depends on the USB peripheral. For devices with limited RAM or USB buffer the
/// setting can be reduced (valid range is 1 .. 255).
#define DAP_PACKET_COUNT 1U ///< Specifies number of packets buffered.
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

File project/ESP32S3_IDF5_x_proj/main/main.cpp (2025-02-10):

/*
 * @Author: wpqds666@163.com MGodmonkey
 * @Date: 2024-11-15 23:24:33
 * @LastEditors: wpqds666@163.com MGodmonkey
 * @LastEditTime: 2024-12-23 16:01:21
 * @FilePath: \ESP32-Debugger\main\main.cpp
 * @Description: 
 * 
 * Copyright (c) 2024 by MGodmonkey, All Rights Reserved.
 */
#include "main.h"

static const char *TAG = "main";
TaskHandle_t kDAPTaskHandle = NULL;
TaskHandle_t ws2812_task_handle = NULL;
TaskHandle_t kWifiTcpServerTaskhandle = NULL;
// extern int kRestartDAPHandle;

static volatile bool current_mode = DEFAULT_DEBUG_MODE;
static RTC_NOINIT_ATTR uint8_t laster_mode;
static RTC_NOINIT_ATTR uint8_t is_first_boot;
// extern httpd_handle_t http_server;

extern "C" void tcp_server_task(void *pvParameters);
extern "C" void DAP_Thread(void *pvParameters);

extern "C" uint16_t tud_hid_get_report_cb(uint8_t instance, uint8_t report_id, hid_report_type_t report_type, uint8_t *buffer, uint16_t reqlen)
{
    return 0;
}

extern "C" void tud_hid_set_report_cb(uint8_t instance, uint8_t report_id, hid_report_type_t report_type, uint8_t const *buffer, uint16_t bufsize)
{
    static uint8_t s_tx_buf[CFG_TUD_HID_EP_BUFSIZE];

    DAP_ProcessCommand(buffer, s_tx_buf);
    tud_hid_report(0, s_tx_buf, sizeof(s_tx_buf));
}

// 有线调试配置
tinyusb_config_t tusb_cfg = {
    .device_descriptor = NULL,
    .string_descriptor = NULL,
    .string_descriptor_count = 0,
    .external_phy = false,
    .configuration_descriptor = NULL,
    .self_powered = false,
    .vbus_monitor_io = 0};

tinyusb_config_cdcacm_t acm_cfg = {
    .usb_dev = TINYUSB_USBDEV_0,
    .cdc_port = TINYUSB_CDC_ACM_0,
    .rx_unread_buf_sz = 64,
    .callback_rx = usb_cdc_send_to_uart, // the first way to register a callback
    .callback_rx_wanted_char = NULL,
    .callback_line_state_changed = NULL,
    .callback_line_coding_changed = usb_cdc_set_line_codinig};

// 无线调试串口初试化
void uart_init(void) {
    uart_config_t uart_config = {
        .baud_rate = 115200,
        .data_bits = UART_DATA_8_BITS,
        .parity    = UART_PARITY_DISABLE,
        .stop_bits = UART_STOP_BITS_1,
        .flow_ctrl = UART_HW_FLOWCTRL_DISABLE,
        .source_clk = UART_SCLK_APB,
    };
    
    // 配置 UART 参数
    ESP_ERROR_CHECK(uart_param_config(UART_PORT, &uart_config));
    ESP_ERROR_CHECK(uart_set_pin(UART_PORT, GPIO_UART_TX, GPIO_UART_RX, UART_PIN_NO_CHANGE, UART_PIN_NO_CHANGE));
    ESP_ERROR_CHECK(uart_driver_install(UART_PORT, 1024, 1024, 0, NULL, 0));
}

// 按钮初试化
static void key_init(void)
{
    gpio_config_t io_conf = {};

    io_conf.intr_type = GPIO_INTR_DISABLE;
    io_conf.mode = GPIO_MODE_INPUT;
    io_conf.pin_bit_mask = (1ULL << MODE_SWITCH_GPIO);
    io_conf.pull_up_en = GPIO_PULLUP_ENABLE;
    io_conf.pull_down_en = GPIO_PULLDOWN_DISABLE;
    gpio_config(&io_conf);
    gpio_set_level(MODE_SWITCH_GPIO, 1);
}

// 按键状态枚举
typedef enum {
    BUTTON_IDLE,         // 空闲状态
    BUTTON_PRESSED,      // 按下状态，正在计时
    BUTTON_TRIGGERED     // 已触发模式切换
} button_state_t;


// 模式切换任务
static void mode_switch_task(void *pvParameters)
{
    button_state_t button_state = BUTTON_IDLE;
    TickType_t press_start_time = 0;
    const TickType_t mode_switch_threshold = pdMS_TO_TICKS(LONG_PRESS_TIME_MS);
    
    while (1) {
        int level = gpio_get_level(MODE_SWITCH_GPIO);
        TickType_t current_time = xTaskGetTickCount();
        
        switch (button_state) {
            case BUTTON_IDLE:
                if (level == 0) {  // 按键按下
                    press_start_time = current_time;
                    button_state = BUTTON_PRESSED;
                }
                break;
                
            case BUTTON_PRESSED:
                if (level == 0) {  // 按键持续按下
                    if ((current_time - press_start_time) >= mode_switch_threshold) {
                        // 达到触发时间，执行模式切换
                        button_state = BUTTON_TRIGGERED;
                        log_printf(TAG, LOG_INFO, "Mode switch triggered");

                        if (current_mode == WIRELESS_MODE)
                        {
                            ws2812_task_handle = NULL;
                            ws2812_set_color(LED_COLOR_BLACK);
                            wifi_stop();
                        }

                        // 保存新模式
                        laster_mode = !current_mode;
                        
                        // 橙灯闪烁两次表示模式切换
                        ws2812_blink(500, 2, LED_COLOR_ORANGE);
                        
                        // 执行软复位
                        esp_restart();
                        
                    }
                } else {  // 按键释放
                    button_state = BUTTON_IDLE;
                }
                break;
                
            case BUTTON_TRIGGERED:
                if (level == 1) {  // 等待按键释放
                    button_state = BUTTON_IDLE;
                }
                break;
        }
        
        vTaskDelay(pdMS_TO_TICKS(10));  // 10ms采样间隔
    }
}

extern "C" void app_main(void)
{

    // 检查是否首次启动
    if (is_first_boot != 0x55) {
        is_first_boot = 0x55;
        laster_mode = DEFAULT_DEBUG_MODE;
    }
    
    current_mode = laster_mode;
    ws2812_init();
    ws2812_breath(LED_COLOR_ORANGE, 2000);
    key_init();
    DAP_Setup();
    
    // 增加模式切换任务的栈大小
    xTaskCreate(mode_switch_task, "mode_switch", 4096, NULL, 5, NULL);

    // 根据默认模式初始化
    if (current_mode == WIRELESS_MODE)
    {
        cdc_uart_init(UART_PORT, GPIO_UART_TX, GPIO_UART_RX, 115200, false);
        wifi_init();

        xTaskCreate(ws2812_task, "ws2812_task", 4096, NULL, 5, &ws2812_task_handle);
        xTaskCreate(tcp_server_task, "tcp_server", 4096, NULL, 14, &kWifiTcpServerTaskhandle);
    }
    else 
    {
        bool mount_ret = msc_disk_mount(CONFIG_TINYUSB_MSC_MOUNT_PATH);

        if (!mount_ret) {
            log_printf(TAG, LOG_ERROR, "Failed to mount MSC disk");
            ws2812_set_color(LED_COLOR_RED);
        }
        tusb_cfg.configuration_descriptor = get_configuration_descriptor(mount_ret);
        tusb_cfg.string_descriptor = get_string_descriptor(mount_ret);
        tusb_cfg.string_descriptor_count = get_string_descriptor_count();
        tusb_cfg.device_descriptor = get_device_descriptor();

        // 安装 TinyUSB 驱动
        ESP_ERROR_CHECK(tinyusb_driver_install(&tusb_cfg));
        // 初始化 CDC ACM
        ESP_ERROR_CHECK(tusb_cdc_acm_init(&acm_cfg));

        programmer_init();
        
        // 初始化 CDC UART
        cdc_uart_init(UART_PORT, GPIO_UART_TX, GPIO_UART_RX, 115200, true);
        cdc_uart_register_rx_handler(CDC_UART_USB_HANDLER, usb_cdc_send_to_host, (void *)TINYUSB_CDC_ACM_0);

        ws2812_set_color(LED_COLOR_PURPLE);

        log_printf(TAG, LOG_INFO, "USB initialized successfully");
    }

    xTaskCreate(DAP_Thread, "DAP_Task", 2048, NULL, 10, &kDAPTaskHandle);
}

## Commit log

2024-11-16 初步成功的版本
2024-11-18 移除不必要的包
2024-11-26 修改为8M版本
    [partitions.csv]
2024-12-03 能实现无线传输的方案的初步版本
2024-12-05 解决重大bug：esp_tinyusb不能为最新的1.4.5的问题
2024-12-07 添加esp-tinyusb1.5.4包并做一些添加tinyusb_msc_storage_deinit_spiflash函数
2024-12-07 初步能实现无线和有线模式的切换功能,，但有线模式的卸载和重装有问题，且代码没整理
2024-12-20 暂时实现有线/无线使用JTAG和串口协议的一版(但有线无线切换以及串口暂时还有问题)
2024-12-22 准正式的V1.0版本（代码还没规整）
2024-12-23 整洁了一下代码，移除一些非必要文件
2024-12-24 解决双端模式下串口不能同时进行收发的效果
2024-12-24 解决有线和无线不使用同一个串口初试化函数的问题
2024-12-25 V1.0正式版(暂时的)
2024-12-26 移除暂未实现的功能
2024-12-26 更新reademe
2024-12-27 更新README
2025-01-02 修改README
2025-01-15 解决SWD协议下10Mhz以下无法使用的错误
2025-01-15 添加一些忽略文件
2025-02-10 暂存的重构目录结构
    [partitions.csv, partitions_16M.csv]
2025-02-10 修正wifi端口冲突
2025-02-13 补充完整文件
    [发送机底部.SLDPRT, 发送机底部.STL, 发送机顶盖.SLDPRT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]
2026-01-05 Fix formatting in README for wireless mode section
